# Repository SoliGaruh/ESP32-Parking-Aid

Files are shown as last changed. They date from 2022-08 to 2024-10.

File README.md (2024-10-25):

# ESP32-Parking-Aid

Illuminates an RGB LED based on the distance an object is away from the HC-SR04 ultrasonic
sensor. It was developed to assist parking a car in a garage.

The RGB LED's red, green and blue pins are connected to PIN_RED, PIN_GREEN and PIN_BLUE.

A 220 ohm resitor is connected inline between each of the LED colour pins and the corresponding ESP32
GPIO ports. The LED's GND is connected to GND on the ESP32.

The wiring for the HC-SR04 is shown in the file "ESP32 HC-SR04 Wiring.png". The HC-SR04 is used
as it supports the 3.3V logic of the ESP32.

A trimpot is used to adjust the measured stopping distance. The trimpot can increase the distance at which the blue and then red LEDs are illuminated. As a safety measure, the trimpot only ever adds to the distances and is never used to subtract distance. Subtraction could result in an accident.

The system is connected to mains power so there has been no consideration to power this from a
battery.

This project does not depend on any libraries.

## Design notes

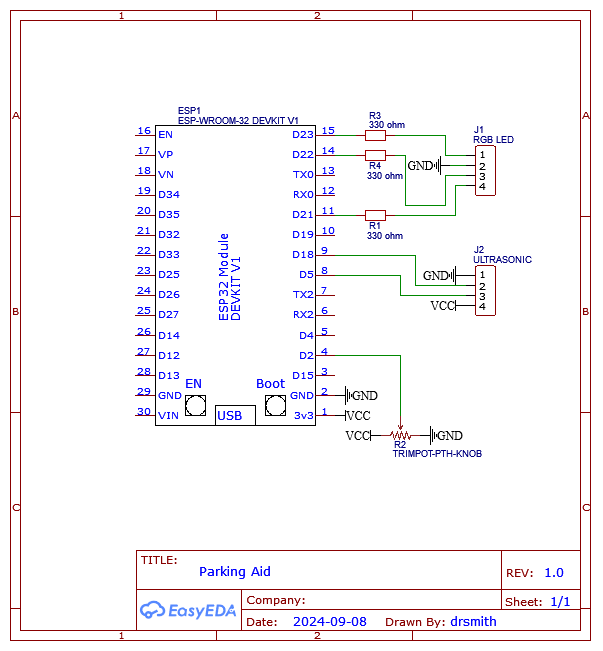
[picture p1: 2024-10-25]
Schematic_Parking-Aid_2024-09-09.png

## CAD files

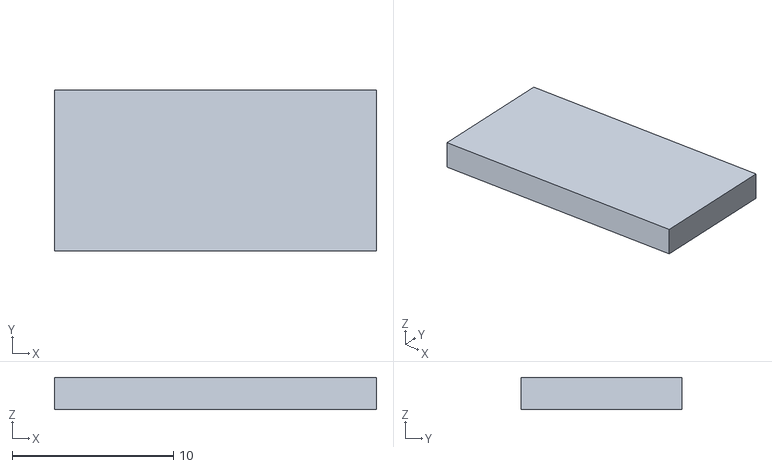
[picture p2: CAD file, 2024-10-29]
Parking Aid PCB Pad v2.stl
20.0 x 10.0 x 2.00

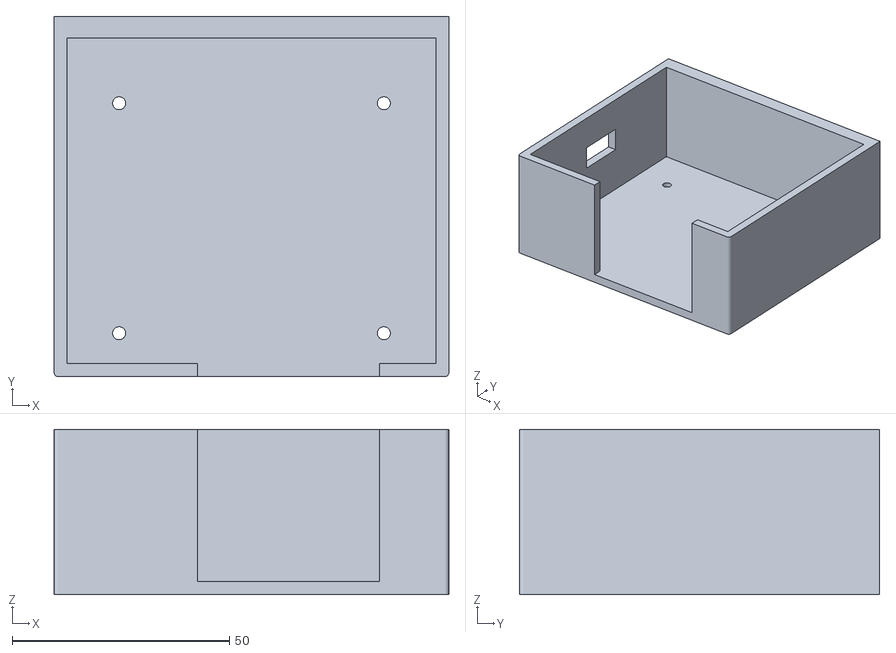
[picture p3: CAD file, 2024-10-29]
Parking Aid PCB Box v2.stl
91.0 x 83.0 x 38.0

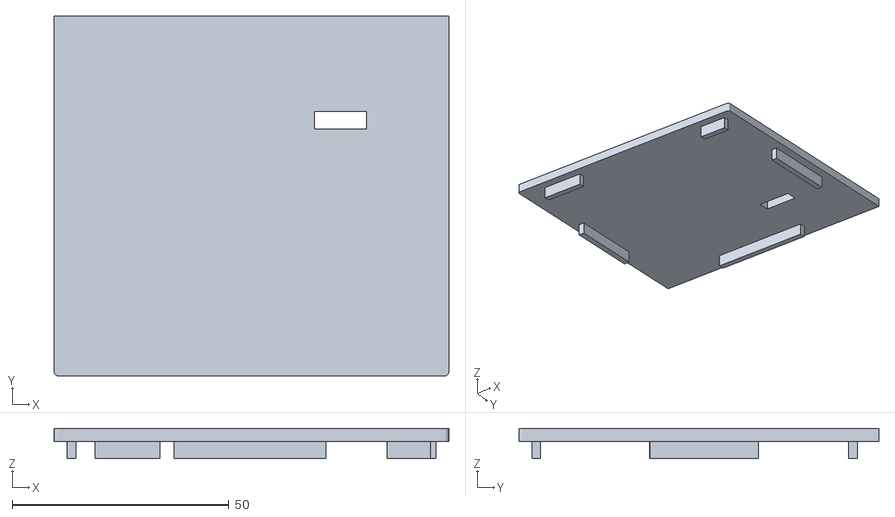
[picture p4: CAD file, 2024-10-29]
Parking Aid PCB Lid v2.stl
91.0 x 83.0 x 7.00

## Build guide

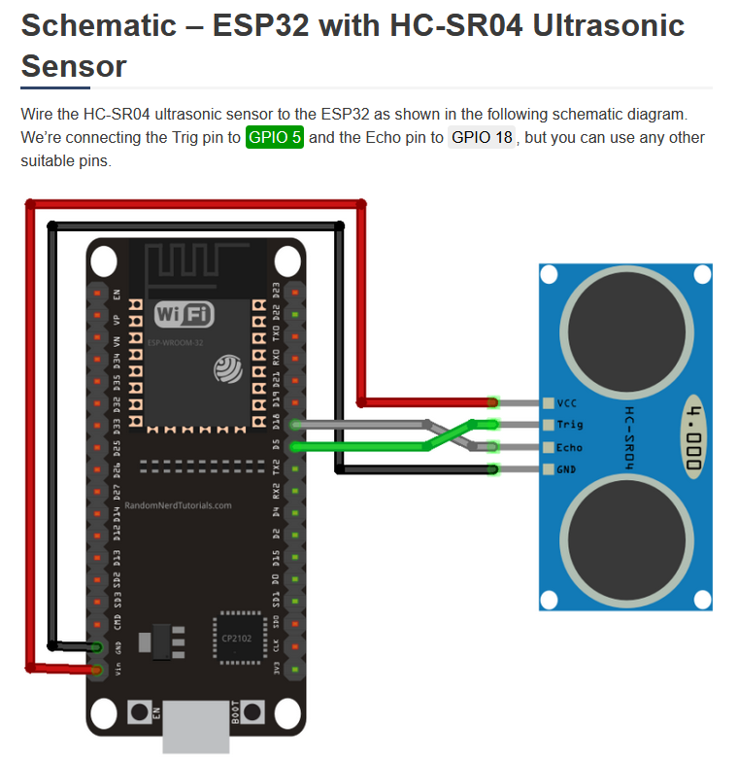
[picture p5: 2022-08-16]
ESP32 HC-SR04 Wiring.png

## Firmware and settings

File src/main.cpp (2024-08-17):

/*
 Copyright (C) 2022 Steve Tattersall

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
 THE SOFTWARE IS PROVIDED "AS IS", WITHOUT WARRANTY OF ANY KIND, EXPRESS OR
 IMPLIED, INCLUDING BUT NOT LIMITED TO THE WARRANTIES OF MERCHANTABILITY,
 FITNESS FOR A PARTICULAR PURPOSE AND NONINFRINGEMENT. IN NO EVENT SHALL THE
 AUTHORS OR COPYRIGHT HOLDERS BE LIABLE FOR ANY CLAIM, DAMAGES OR OTHER
 LIABILITY, WHETHER IN AN ACTION OF CONTRACT, TORT OR OTHERWISE, ARISING FROM,
 OUT OF OR IN CONNECTION WITH THE SOFTWARE OR THE USE OR OTHER DEALINGS IN
 THE SOFTWARE.
*/

#include <Arduino.h> // required for MS VS Code and PlatformIO IDE

// The resolution in bits to use for the analogRead() function
#define ANALOG_READ_RESOLUTION 12

// the pin the trimport is connected to
#define PIN_POT 2

// RGB LED pins
#define PIN_RED 23   // GIOP23
#define PIN_GREEN 22 // GIOP22
#define PIN_BLUE 21  // GIOP21

// Ultrasonic sensor pins
#define PIN_TRIGGER 5
#define PIN_ECHO 18

// The speed of sound in cm per microsecond
#define SOUND_SPEED 0.0343

// Threshold distances in cm used to set the colour of the LED
#define WARN_DIST 200
#define STOP_DIST 65

// Maximum distance in cm that the trimpot can adjust the threshold distances towards the garage door. 
// The minimum value is always zero. On the ESP32, the trimpot mapping used is 
// map(...,0,4095,0,MAX_DISTANCE_OFFSET).
#define MAX_DISTANCE_OFFSET 30

// This is how long the LED will stay lit once the car is parked.
#define PARKED_LED_ONTIME_MS 30000 // 30 seconds

// enum representing where the car is
enum carLocation_enum : char
{
  unknown = 0,
  longRange,
  mediumRange,
  shortRange
};

// car location is initialsed to unknown to ensure the system lights up an LED on startup
carLocation_enum carLocation = unknown;

// time (millis()) when the car enters short range. This is used to determine how long the
// LED will remain lit when the car is parked.
unsigned long shortRangeStartTime;

// used to determine whether the LED has been switched off due to the car being in short range for LED_PARKED_ONTIME_MS ms.
// Assumed parked.
bool ledTimedOut = false;

// used for distance sensor calculations
long duration;
float distanceCm;

// trimpot mapped offset value
long mappedOffsetValue;

// Maximum trimpot value
const long MaxTrimPotValue = (1 << ANALOG_READ_RESOLUTION) - 1;

// Initialise the Serial monitor and the GPIO pins
void setup()
{
  Serial.begin(115200); // Starts the serial communication
  delay(500);

  // Ultrasonic sensor pins
  pinMode(PIN_TRIGGER, OUTPUT);
  pinMode(PIN_ECHO, INPUT);

  // LED pins
  pinMode(PIN_RED, OUTPUT);
  pinMode(PIN_GREEN, OUTPUT);
  pinMode(PIN_BLUE, OUTPUT);

  // Trimpot pin
  pinMode(PIN_POT, INPUT);

  // Set the analog read resolution in bits. I'm trying to ensure that it is always the same for all
  // boards, to ensure the map() function used below works properly.
  analogReadResolution(ANALOG_READ_RESOLUTION);
}

void loop()
{
  // The mapped offset is added to both the warning and stopping distance when determining the position of 
  // the car and the colour of the LED.
  mappedOffsetValue = map(analogRead(PIN_POT), 0, MaxTrimPotValue, 0, MAX_DISTANCE_OFFSET);

  // Prints the distance offset to the Serial Monitor
  Serial.print("Distance Offset (cm) [0 - 30] : ");
  Serial.println(mappedOffsetValue);

  // Clears the trigPin
  digitalWrite(PIN_TRIGGER, LOW);
  delayMicroseconds(2);

  // Sets the trigPin on HIGH state for 10 microseconds
  digitalWrite(PIN_TRIGGER, HIGH);
  delayMicroseconds(10);
  digitalWrite(PIN_TRIGGER, LOW);

  // Reads the echoPin, returns the sound wave travel time in microseconds
  duration = pulseIn(PIN_ECHO, HIGH);

  // Calculate the distance
  distanceCm = duration * SOUND_SPEED / 2;

  // Prints the car's distance to the Serial Monitor
  Serial.print("Distance (cm): ");
  Serial.println(distanceCm);

  //! IMPORTANT: Never subtract the trimpot's mapped offset value from the threshold distance. Subtraction could
  //! result in the calculated threshold distance being too close to the sensor resulting in an accident.
  if (distanceCm > WARN_DIST + mappedOffsetValue)
  {
    // the point here and below is not to write to the LED pins if the right colour is already set.
    if (carLocation != longRange)
    {
      analogWrite(PIN_RED, 0);
      analogWrite(PIN_GREEN, 255);
      analogWrite(PIN_BLUE, 0);

      carLocation = longRange;
      Serial.println("LONG");
    }
  }

  //! IMPORTANT: Never subtract the trimpot's mapped offset value from the threshold distance. Subtraction could
  //! result in the calculated threshold distance being too close to the sensor resulting in an accident.
  else if (distanceCm > (STOP_DIST + mappedOffsetValue))
  {
    if (carLocation != mediumRange)
    {
      analogWrite(PIN_RED, 0);
      analogWrite(PIN_GREEN, 0);
      analogWrite(PIN_BLUE, 255);

      Serial.println("MEDIUM");

      carLocation = mediumRange;
    }
  }

  //! IMPORTANT: Never subtract the trimpot's mapped offset value from the threshold distance. Subtraction could
  //! result in the calculated threshold distance being too close to the sensor resulting in an accident.
  else if (distanceCm <= (STOP_DIST + mappedOffsetValue))
  {
    if (carLocation != shortRange)
    {
      // record the current time to determine when to turn off the red LED
      shortRangeStartTime = millis();
      ledTimedOut = false;

      analogWrite(PIN_RED, 255);
      analogWrite(PIN_GREEN, 0);
      analogWrite(PIN_BLUE, 0);

      Serial.println("SHORT");

      carLocation = shortRange;
    }

    // turn off the red LED if it has been on for LED_PARKED_ONTIME_MS milliseconds
    if (millis() - shortRangeStartTime > PARKED_LED_ONTIME_MS)
    {
      // switch off the LED if it hasn't already been switched off
      if (!ledTimedOut)
      {
        Serial.println("TIMEOUT : LED off");
        analogWrite(PIN_RED, 0);
        analogWrite(PIN_GREEN, 0);
        analogWrite(PIN_BLUE, 0);

        ledTimedOut = true;
      }
    }
  }

  // checking the distance 5 times/s is adequate
  delay(200);
}

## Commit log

2024-09-09 added schematic
2024-10-29 Added 3D printer STL files for the box
    [Parking Aid PCB Box v2.stl, Parking Aid PCB Lid v2.stl, Parking Aid PCB Pad v2.stl]
